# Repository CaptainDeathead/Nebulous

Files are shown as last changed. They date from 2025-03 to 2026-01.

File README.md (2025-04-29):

# Nebulous

Nebulous is a retro console system powered by a Raspberry Pi. Designed for both nostalgia and innovation, it offers a unique blend of custom hardware and software to deliver an exciting multiplayer gaming experience.

## Features

- **Custom Controllers**: Nebulous supports up to 4 controllers for multiplayer gaming.
- **SD Card Cartridges**: Games are loaded via SD card cartridges, offering a retro game-swapping experience.
- **3D Printed Shell**: The physical console is encased in a sleek and durable 3D-printed shell.
- **Custom Games**: Includes a variety of games designed specifically for Nebulous (see the list below).
- **NES Game Support**: Play classic `.nes` files for old NES games.

## Custom Games

The `games` directory contains the following games created specifically for Nebulous using Pygame:

- **Caliby**: A calibration tool for testing controllers with the Nebulous.
- **Meteors**: A 4-player Asteroids clone.
- **Pong**: The classic Pong game.
- **Shape Royale**: A class-based battle royale where you play as 2D shapes.
- **Snither**: A multiplayer merge of Slither.io and classic Snake.
- **Tetris**: A 4-player version of the timeless Tetris game.

## Design Files

All files related to the physical design of Nebulous are located in the `/design` directory, including:

- **3D Printing Files**: Models for the Nebulous shell.
- **Controller PCB Designs**: Schematics and layouts for custom controllers.
- **Wiring Designs**: Diagrams and plans for wiring the console, controllers, and other components.

## How It Works

- **Without Cartridge**: If no game cartridge is inserted, the console will prompt you to insert one.
- **With Cartridge**: When a cartridge is inserted, the console attempts to load and play the game.

## Getting Started

1. **Hardware Setup**:
   - Assemble the 3D-printed case using files from the `/design` directory.
   - Connect up to 4 custom controllers using the provided PCB and wiring designs.
   - Insert an SD card cartridge containing your desired game.

2. **Software Setup**:
   - Clone the repository:
     ```bash
     git clone https://github.com/CaptainDeathead/Nebulous.git
     ```
   - Navigate to the `rpi-install` directory and run the `install.sh` script to set up the console:
     ```bash
     cd Nebulous/rpi-install
     ./install.sh
     ```

3. **Running Games**:
   - Insert a game cartridge to start playing.
   - Alternatively, load a `.nes` file for older NES games.

## Contributing

Contributions are welcome! Feel free to submit pull requests or open issues for bug reports and feature suggestions.

## License

This project is licensed under the MIT License - see the [LICENSE](LICENSE) file for details.

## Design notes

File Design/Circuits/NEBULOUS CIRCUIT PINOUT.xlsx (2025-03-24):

USE | PIN INFO | PINS L | PINS R | PIN INFO | USE | USE | PINS L |  | PINS R | USE | USE | PINS
MAIN BRIDGE 3V POWER |  | 3.3V | 5V |  | CARTRIDGE READER 5V POWER | C0 DPAD + SELECT | CH0 |  | 3.3V IN | MAIN BRIDGE 3.3V POWER | MAIN BRIDGE 3.3V GND | GND
 | I2C | SDA | 5V |  |  | C0 ABXY + START | CH1 |  | 3.3V IN | MAIN BRIDGE 3.3V POWER | MAIN BRIDGE 3.3V POWER | 3.3V IN
 | I2C | SCL | GROUND |  | CARTRIDGE READER 5V GND | C1 DPAD + SELECT | CH2 |  | GND | MAIN BRIDGE 3.3V GND | CARTRIDGE READER 5V POWER | 5V IN
 |  | GPIO 4 | TX | UART |  | C1 ABXY + START | CH3 | MCP3008 | CLK | SPI BRIDGE - SCLK | CE1 GPIO 7 | CE1 | CARTRIDGE READER | CARTRIDGE
MAIN BRIDGE 3V GND |  | GROUND | RX | UART |  | C2 DPAD + SELECT | CH4 | MCP3008 | MISO | SPI BRIDGE - MSIO | SPI BRIDGE - MOSI | MOSI | CARTRIDGE READER | CARTRIDGE
 |  | GPIO 17 | GPIO 18 |  | CONSOLE FRONT ON / OFF SIGNAL | C2 ABXY + START | CH5 |  | MOSI | SPI BRIDGE - MOSI | SPI BRIDGE - SCLK | SCLK
 |  | GPIO 27 | GROUND |  |  | C3 DPAD + SELECT | CH6 |  | CE0 | CE0 GPIO 8 | SPI BRIDGE - MISO | MISO
 |  | GPIO 22 | GPIO 23 |  |  | C3 ABXY + START | CH7 |  | GND | MAIN BRIDGE 3.3V GND | CARTRIDGE READER 5V GND | GND
CONSOLE MANAGEMENT 3.3V POWER |  | 3.3V | GPIO 24
SPI BRIDGE - MCP3008 / CARTRIDGE READER | SPI | MOSI | GROUND
SPI BRIDGE - MCP3008 / CARTRIDGE READER | SPI | MISO | GPIO 25
SPI BRIDGE - MCP3008 / CARTRIDGE READER | SPI | SCLK | CE0 GPIO 8 | SPI | MCP3008 - CHIP SELECT
CONSOLE MANAGEMENT 3.3V GND |  | GROUND | CE1 GPIO 7 | SPI | CARTRIDGE READER - CHIP SELECT
 | RESERVED | GPIO 1 | GPIO 0 | RESERVED
CONTROLLER 0 STATUS INPUT |  | GPIO 5 | GROUND
CONTROLLER 1 STATUS INPUT |  | GPIO 6 | GPIO 12
CONTROLLER 2 STATUS INPUT |  | GPIO 13 | GROUND
CONTROLLER 3 STATUS INPUT |  | GPIO 19 | GPIO 16
 |  | GPIO 26 | GPIO 20
 |  | GROUND | GPIO 21

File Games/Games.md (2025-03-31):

# Game information for Nebulous

## Format
1. Games must be made in any way that involves a single graphical window that must run on a raspberry pi with no DE (Desktop Environment).
2. Games should be shipped in cartridges which will plug into the exterior of the console.
3. Games should be made compatible with at least one of the availiable controllers for the console.
4. Games should provide appropriate information of their age restrictions and content contained.

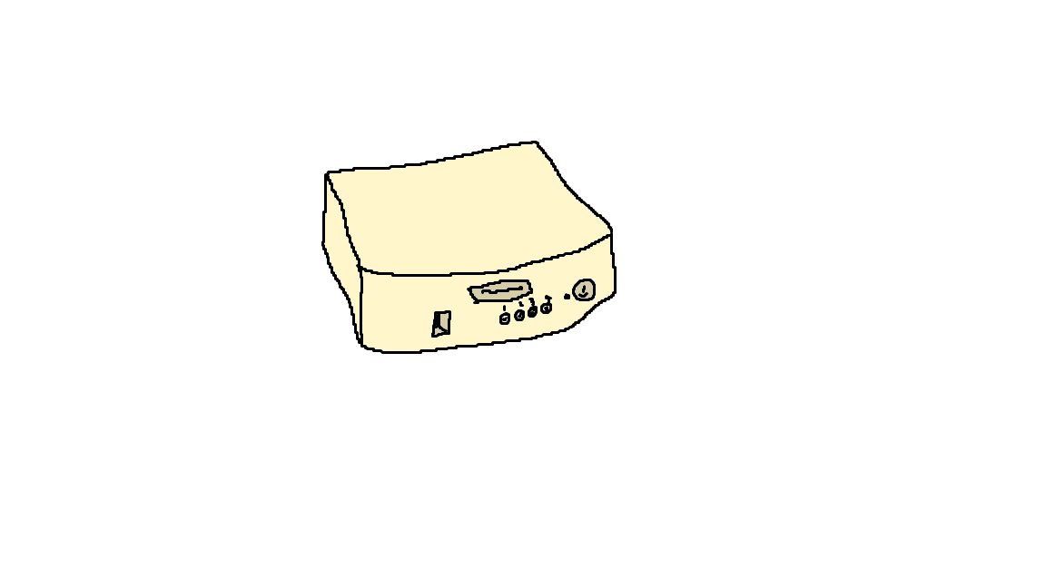
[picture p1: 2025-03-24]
Design/Sketches/CONSOLE BASE DESIGN.png

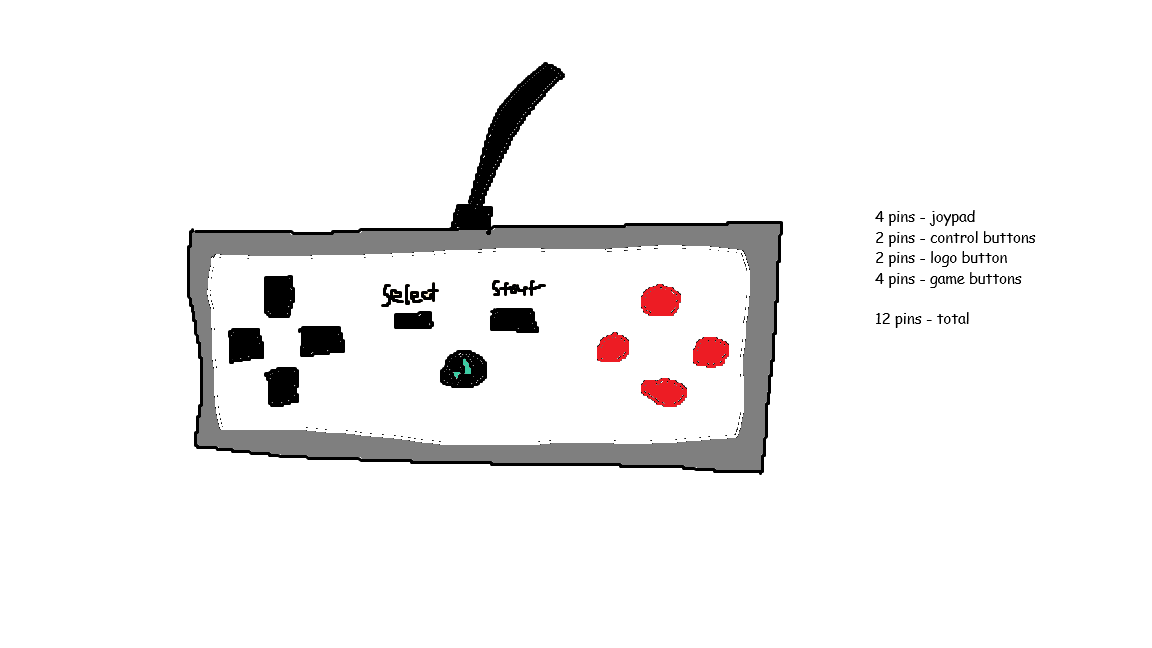
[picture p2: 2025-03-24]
Design/Sketches/CONTROLLER IDEA DESIGN (PINS NOT CORRECT).png

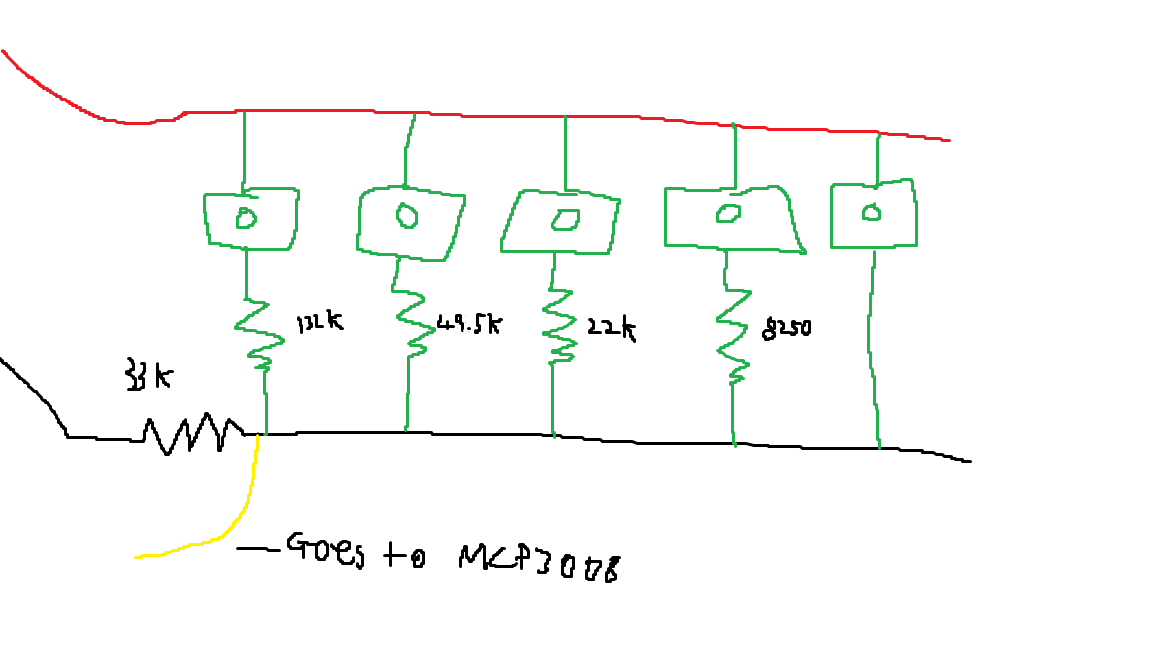
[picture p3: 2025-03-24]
Design/Sketches/ROUGH CONTROLLER CIRCUIT.png

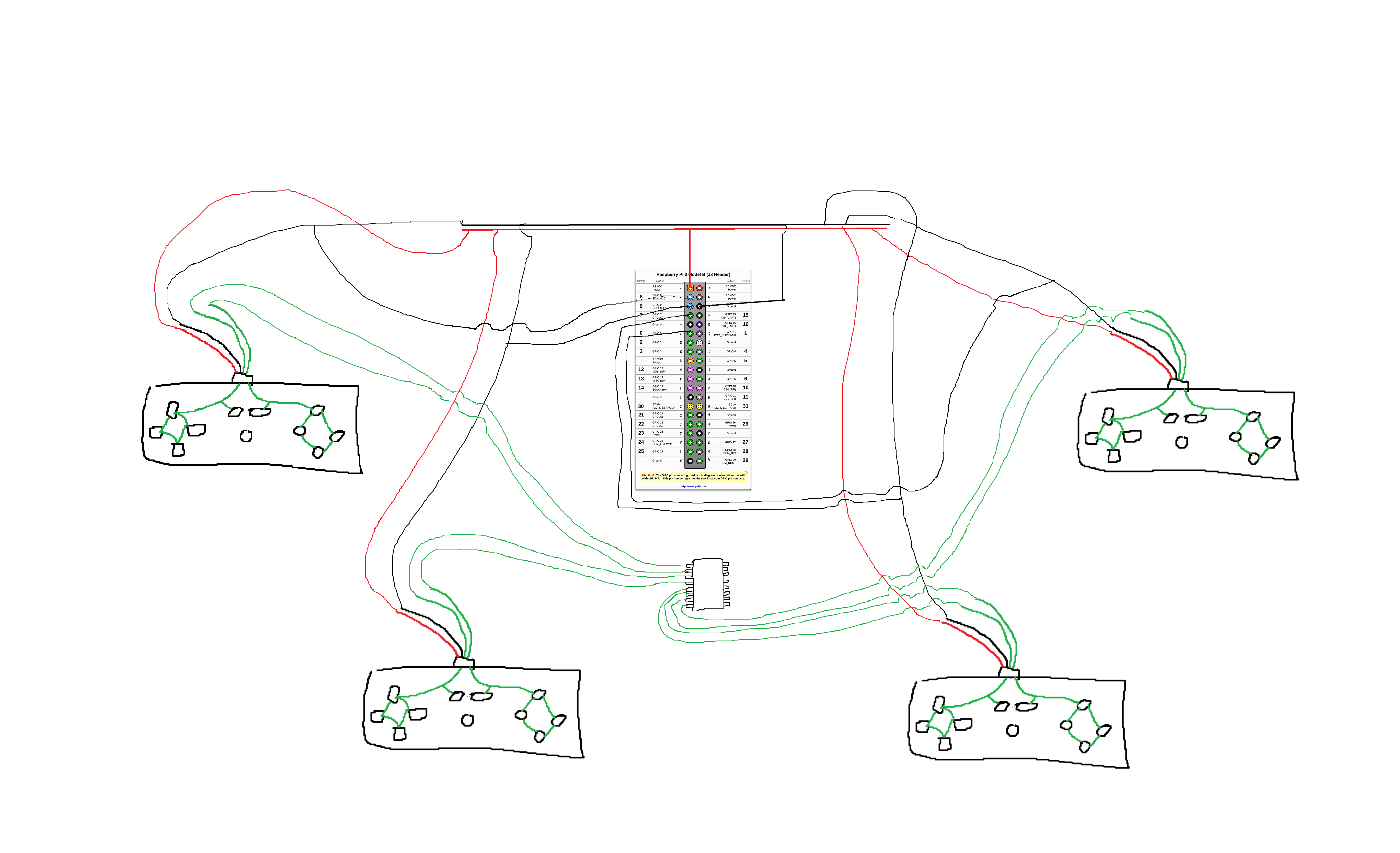
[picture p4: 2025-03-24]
Design/Sketches/ROUGH CIRCUIT (PINS NOT CORRECT).png

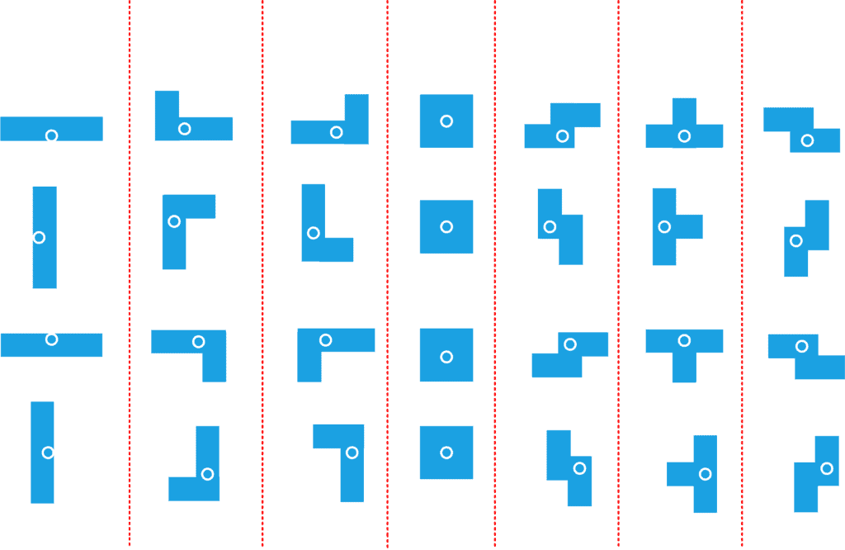
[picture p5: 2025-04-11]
Games/Tetris/rotations.png

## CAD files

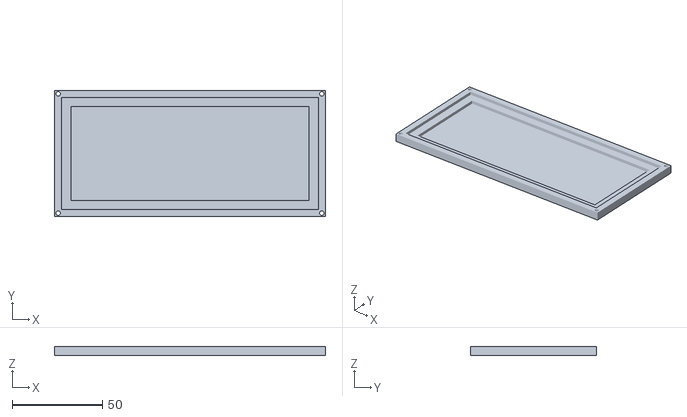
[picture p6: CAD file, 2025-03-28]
Design/Controller stls/Shell Bottom v3.stl
150.0 x 70.0 x 5.00

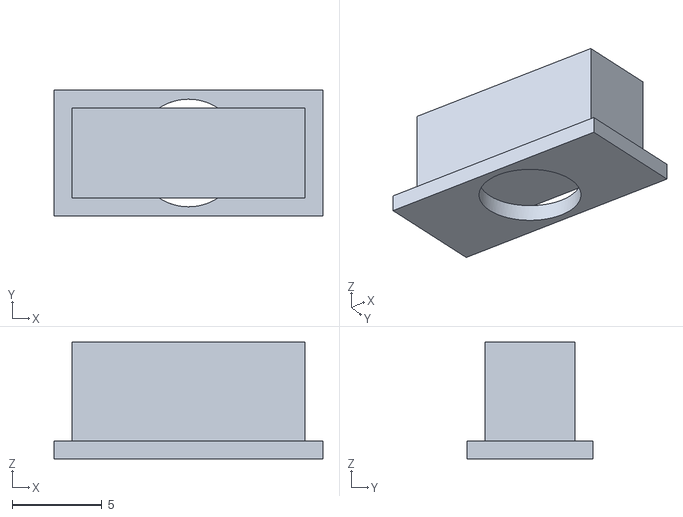
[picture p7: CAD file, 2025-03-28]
Design/Controller stls/Select-Start v1.stl
15.0 x 7.00 x 6.50

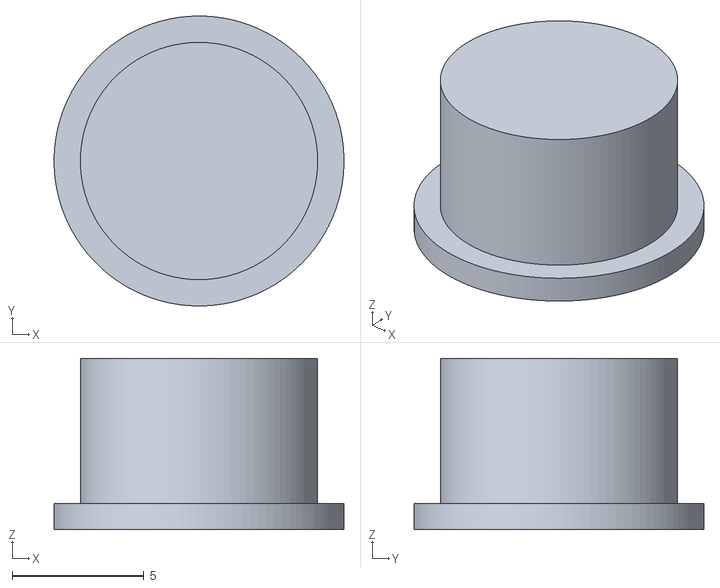
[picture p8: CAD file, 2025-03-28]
Design/Controller stls/ABCD v2.stl
11.0 x 11.0 x 6.50

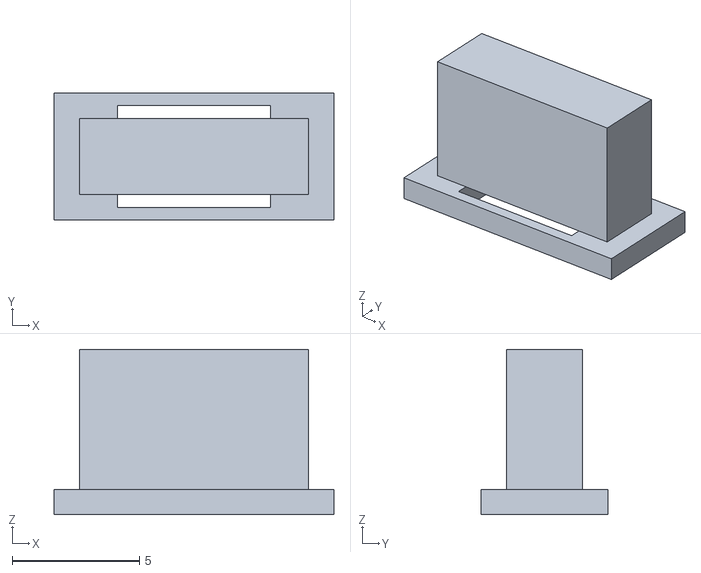
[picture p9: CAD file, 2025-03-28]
Design/Controller stls/D-Pad v1.stl
11.0 x 5.00 x 6.50

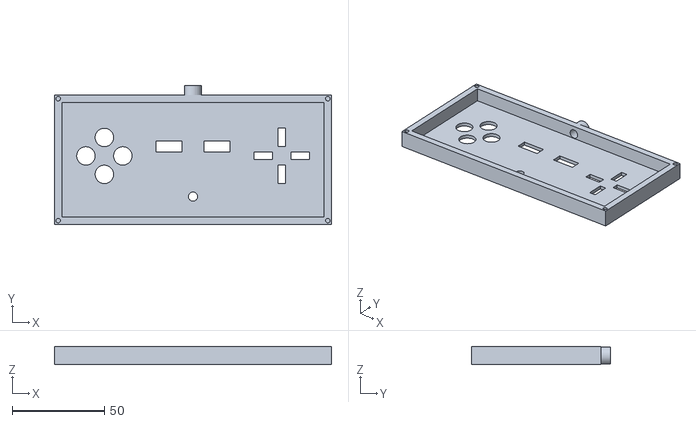
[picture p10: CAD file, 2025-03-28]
Design/Controller stls/Shell Top v5.stl
150.0 x 75.0 x 10.0

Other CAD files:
Design/Main Console stls/Nebulous Base.f3d
Design/Main Console stls/Nebulous Roof.f3d
Design/Main Console stls/Nebulous Visual (DO NOT USE IN PRINTER) v1.f3z

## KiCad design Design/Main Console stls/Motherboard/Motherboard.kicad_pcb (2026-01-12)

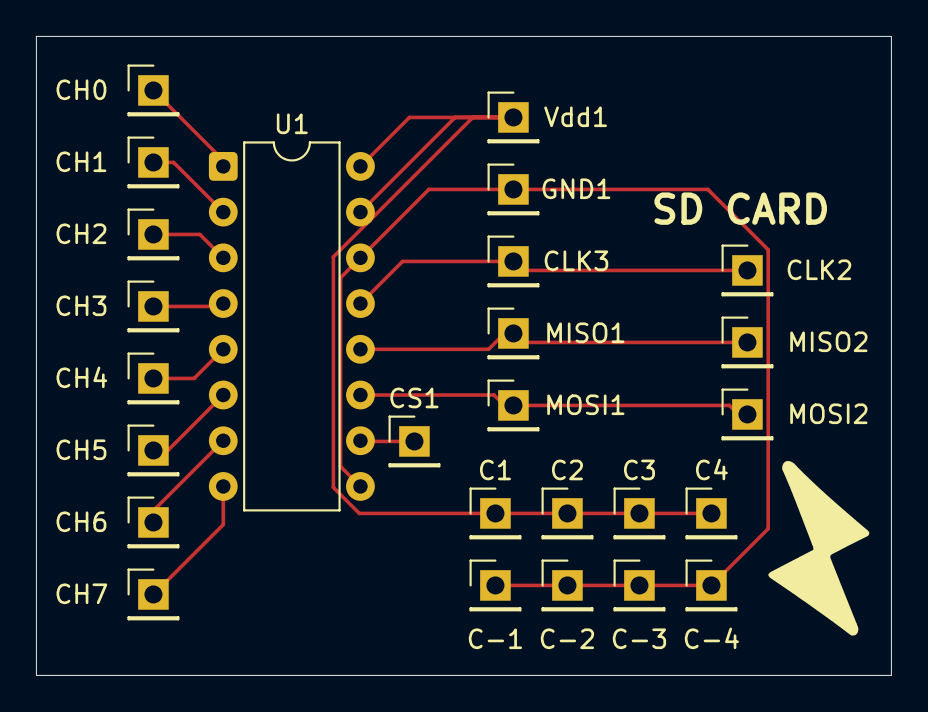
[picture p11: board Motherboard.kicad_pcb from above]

Board: 2 copper layers, 47.5 x 35.5 mm, 26 parts (0 on the bottom side), 14 nets.

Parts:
C1, C2, C3, C4: TestPoint; PinHeader_1x01_P2.54mm_Vertical
C-1, C-2, C-3, C-4: TestPoint; PinHeader_1x01_P2.54mm_Vertical
CH0, CH1, CH2, CH3, CH4, CH5, CH6, CH7: TestPoint; PinHeader_1x01_P2.54mm_Vertical
CLK2, CLK3: TestPoint; PinHeader_1x01_P2.54mm_Vertical
CS1: TestPoint; PinHeader_1x01_P2.54mm_Vertical
GND1: TestPoint; PinHeader_1x01_P2.54mm_Vertical
MISO1, MISO2: TestPoint; PinHeader_1x01_P2.54mm_Vertical
MOSI1, MOSI2: TestPoint; PinHeader_1x01_P2.54mm_Vertical
U1: MCP3008; DIP-16_W7.62mm
Vdd1: TestPoint; PinHeader_1x01_P2.54mm_Vertical

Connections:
unnamed: C-1.1, C-2.1, C-3.1, C-4.1, GND1.1, U1.9 (DGND), U1.14 (AGND)
unnamed: CH0.1, U1.1 (CH0)
unnamed: CH1.1, U1.2 (CH1)
unnamed: CH2.1, U1.3 (CH2)
unnamed: CH3.1, U1.4 (CH3)
unnamed: CH4.1, U1.5 (CH4)
unnamed: CH5.1, U1.6 (CH5)
unnamed: CH6.1, U1.7 (CH6)
unnamed: CH7.1, U1.8 (CH7)
unnamed: CLK2.1, CLK3.1, U1.13 (CLK)
unnamed: MOSI1.1, MOSI2.1, U1.11 (Din)
unnamed: MISO1.1, MISO2.1, U1.12 (Dout)
unnamed: C1.1, C2.1, C3.1, C4.1, U1.15 (Vref), U1.16 (Vdd), Vdd1.1
unnamed: CS1.1, U1.10 (~CS/SHDN)

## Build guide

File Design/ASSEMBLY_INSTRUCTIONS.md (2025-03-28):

# Quick & Easy Recipe for a Flavourful Nebulous

## Ingredients:
- 1x MCP3008 ADC
- 1x Breadboard
- 1x Raspberry Pi (any / 3a+ suggested minimum requirement)
- 1x XC4386 Arduino Compatable SD card interface module
- 4x Nebulous Controller PCB (or breadboarded equivilent)
- 40x Those specific switches (or breadboard equivilent __Only if not using the pcb__)
- 8x 33kΩ resistors
- 8x 8250Ω resistors
- 8x 22kΩ resistors
- 8x 49500Ω resistors
- 8x 132kΩ resistors
- 4x 4 pin socket (any type)
- 4x 4 pin plug (matching socket)
- 4x Generic led
- 4x Resistor matching generic led
- 1x Nebulous Base 3d Printed
- 1x Nebulous Roof 3d Printed
- 16x ABCD 3d Printed
- 16x D-Pad 3d Printed
- 8x Select-Start 3d Printed
- 4x Controller Shell top 3d Printed
- 4x Controller Shell bottom 3d Printed

## Method:
> [!NOTE]
> If not using a pcb for the controller, ignore step 1 and see the bottom of the page for alternative instructions on breadboarding.
1. For each Nebulous Controller PCB, soldier in all the buttons and resistors into their labeled positions, as well as the generic led. Soldier the ends of the positive, ground, data 1, and data 2 wires to the pcb in their respective positions.
2. Screw each Nebulous Controller PCB into a Controller Shell Bottom. Thread the wires connected to the pcb through the outgoing hole in the controller shell top. 
3. Place the ABCD, D-Pad, Select and Start buttons into the controller shell top, and carefully place the controller bottom onto the top, and pull the wires through the hole. Repeat for each controller.
4. Screw the Controller Shell pieces together using the screw holes on the corners. Soldier the wires from each controller to a 4 pin connector. The controllers are now complete.
5. to be continuted

> [!CAUTION]
> Scary

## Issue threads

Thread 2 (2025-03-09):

Snither win condition

Something231, 2025-03-09:
If all players die before the ai, an ai will win by domination even if it has done pretty much nothing, a win by score victory should be added so the snake with the highest score wins when all players die before the ai do.

Closed 2025-03-15.

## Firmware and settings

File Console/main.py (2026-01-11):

import pygame as pg
import random
import logging
import os

from Controllers.controller import Controller
from Controllers.controller_manager import ControllerManager
from cartridge_loader import CartridgeLoader
from console_io import IOManager
from time import sleep, time
from threading import Thread
from sys import argv
from traceback import format_exc

logging.basicConfig()
logging.root.setLevel(logging.DEBUG)
logging.basicConfig(level=logging.DEBUG)

FONTS_PATH = "./UI/Fonts"

class Console:
    """
    FIRMWARE FOR NEBULOUS CONSOLE
    """

    CONSOLE_NAME = "Nebulous REV. A - PROTO"
    TARGET_FIRMWARE_INFO = {
        "CONSOLE_NAME": CONSOLE_NAME,
        "HOST_TYPE": "Linux - Raspberry Pi OS DESKTOP",
        "FIRMWARE_VERSION": "1.1.0",
        "REQUIREMENTS": ["Restart console to load new cartridge (auto detection causing controller lag)"]
    }

    # Allows the console to write data to the cartridge, and verify it is the same to check if cartridge is still inserterd
    # WARNING: THIS CAN CAUSE INTERUPTIONS TO THE CONTROLLER INPUTS (DELAY + GHOSTING)
    # WARNING: THIS CAN HAVE INCONSISTENT BEHAVIOUR WHEN PAIRED WITH CONTROLLERS (RANDOM FAILED READS / WRITES)
    CARTRIDGE_READ_CHECK = False
    USE_CONTROLLER_THREAD = False

    NUM_CONTROLLER_PORTS = 4
    TARGET_FPS = 60 # Only affects menu
    TESTING = False # Allows testing in a non-console environment

    def __init__(self, testing: bool = False, flashing: bool = False) -> None:
        """
        Steps to initialize console:
        1. Initialize console input / output devices (io)
        2. Initialize controllers and controller polling
        3. Initialize display and screen
        4. Load into blank console interface
        5. Initialize cartridge loading
        """

        self.init = False
        self.TESTING = testing
        self.FLASHING = flashing

        logging.info("Welcome from the console!!!\n")

        for key, value in self.TARGET_FIRMWARE_INFO.items():
            logging.info(f"{key}: {value}")

        print()

        self.init_io()
        self.init_controllers()
        self.init_display()
        self.init_menu_interface()
        self.init_cartridges()

        # All threads will read this every time they update and safely shutdown if it is True.
        # Used to shutdown console safely.
        self.kill_threads = False

        self.update_controllers = False # Allows for cartridge reader to "read check" its status 'safely'.
        self.controller_check_thread = Thread(target=self.check_controllers)
        if self.USE_CONTROLLER_THREAD:
            self.controller_check_thread.start()

        self.last_cartridge_update_check = 0
        self.cartridge_check_thread = Thread(target=self.check_cartridge)
        self.cartridge_check_thread.start()

        self.init = True
        logging.info("Console startup complete!")

        if self.TESTING or 1: self.load_cartidge()

        self.main()

    def final_console_shutdown(self) -> None:
        logging.info("Recieved shutdown signal! Don't leave me!!!")

        logging.debug("Waiting for threads to shutdown...")
        self.kill_threads = True
        self.cartridge_check_thread.join()
        if self.USE_CONTROLLER_THREAD:
            self.controller_check_thread.join()

        self.cartridge_loader.unload_cartridge()

        logging.info("Executing 'Nebulous:/Console$ sudo shutdown now'...")
        os.system("sudo shutdown now") # WARNING: Requires 'sudo' to not have a password
        exit(0)

    def init_io(self) -> None:
        logging.info("Initializing console io manager...")

        self.io_manager = IOManager(self.TESTING, self.final_console_shutdown)

    def init_controllers(self) -> None:
        logging.info("Initializing controllers...")

        self.controller_manager = ControllerManager(testing=self.TESTING)

    def init_display(self) -> None:
        logging.info("Initializing display...")

        pg.init()

        try:
            pg.mixer.init(size=32)
        except:
            logging.error("Failed to initialize audio!")
            logging.error(format_exc())


        self.pygame_info = pg.display.Info()
        self.WIDTH = self.pygame_info.current_w
        self.HEIGHT = self.pygame_info.current_h

        self.screen = pg.display.set_mode((self.WIDTH, self.HEIGHT), pg.FULLSCREEN | pg.DOUBLEBUF | pg.HWSURFACE, display=0)

        self.clock = pg.time.Clock()

        pg.mouse.set_visible(False)

    def init_menu_interface(self) -> None:
        logging.info("Initializing menu interface...")

        font = pg.font.Font(f"{FONTS_PATH}/PressStart2P.ttf", 30)

        self.enter_cartridge_surf = font.render("Enter game cartridge...", True, (255, 255, 255))
        self.enter_cartridge_rect = pg.Rect(self.WIDTH // 2 - self.enter_cartridge_surf.width // 2, self.HEIGHT // 2 - self.enter_cartridge_surf.height // 2, self.enter_cartridge_surf.width, self.enter_cartridge_surf.height)
        self.enter_cartridge_vel = [random.choice([3, -3]), random.choice([3, -3])]

    def init_cartridges(self) -> None:
        logging.info("Initializing cartridges...")

        self.cartridge_loader = CartridgeLoader(self.on_title_launch, self.FLASHING)
        self.cartridge_loaded = False

    def load_cartidge(self) -> None:
        self.cartridge_loader.load_cartridge()

    def check_controllers(self) -> None:
        while not self.kill_threads:
            if not self.update_controllers:
                sleep(0.01)
                continue

            self.controller_manager.update()
            sleep(0.01)

    def check_cartridge(self) -> None:
        if self.TESTING: return

        last_cartridge_loaded = self.cartridge_loaded

        while self.cartridge_loader.init_failure:
            if self.kill_threads: return

            self.update_controllers = False

            logging.warning("Attempting to restart cartridge loadeder to reset SD loader (init failure)...")
            self.cartridge_loader.__init__(self.on_title_launch)

            if self.cartridge_loader.init_failure:
                logging.error("Failed to re-init cartridge loader! Waiting 1 second before retrying...")
                sleep(1)

        while not self.kill_threads:
            if self.CARTRIDGE_READ_CHECK:
                if time() - self.last_cartridge_update_check > 2:
                    self.last_cartridge_update_check = time()

                    self.update_controllers = False
                    cartridge_loaded = self.cartridge_loader.is_sd_card_connected()
                    self.update_controllers = True

                    if cartridge_loaded is not None: self.cartridge_loaded = cartridge_loaded

                else:
                    sleep(time() - self.last_cartridge_update_check)

            if not self.cartridge_loaded and self.CARTRIDGE_READ_CHECK:
                self.on_cartridge_remove()
                self.init_cartridges()
                self.check_cartridge()
                return

            elif not last_cartridge_loaded:
                self.cartridge_loaded = True

                if not self.CARTRIDGE_READ_CHECK:
                    logging.warning("Cartridge read checking disabled! Killing cartridge check thread...")
                    return

            #if self.cartridge_loaded: return

    def on_cartridge_remove(self) -> None:
        logging.warning(f"Cartridge no longer reading / writing (disconnected)!")

    def on_game_crash(self) -> None:
        self.screen.fill((255, 0, 0))
        
        title_font = pg.font.Font(f"{FONTS_PATH}/PressStart2P.ttf", 50)
        self.screen.blit(title_font.render("GAME CRASH!", True, (255, 255, 255)), (100, 100))

        instructions_font = pg.font.Font(f"{FONTS_PATH}/PressStart2P.ttf", 30)
        self.screen.blit(instructions_font.render("Restart the console using the front IO switch to safely recover.", True, (0, 255, 255), wraplength=self.WIDTH - 100), (100, 200))

        error_font = pg.font.Font(f"{FONTS_PATH}/PressStart2P.ttf", 20)
        self.screen.blit(error_font.render(f"Error:\n{format_exc()}", True, (0, 0, 0), wraplength=self.WIDTH - 200), (100, 300))

        pg.display.flip()
        
        while 1:
            self.clock.tick(self.TARGET_FPS)

            for event in pg.event.get():
                ...

            self.update()

    def main(self) -> None:
        while not self.cartridge_loaded:
            self.delta_time = self.clock.tick(self.TARGET_FPS)
            self.screen.fill((0, 0, 0))

            for event in pg.event.get():
                if event.type == pg.QUIT:
                    pass

            self.update()

            self.enter_cartridge_rect = self.enter_cartridge_rect.move(self.enter_cartridge_vel[0], self.enter_cartridge_vel[1])

            # Bounce of walls
            if self.enter_cartridge_rect.x <= 0:
                self.enter_cartridge_rect = pg.Rect(0, self.enter_cartridge_rect.y, self.enter_cartridge_rect.w, self.enter_cartridge_rect.h)
                self.enter_cartridge_vel[0] *= -1

            elif self.enter_cartridge_rect.x + self.enter_cartridge_rect.w >= self.WIDTH:
                self.enter_cartridge_rect = pg.Rect(self.WIDTH - self.enter_cartridge_rect.w, self.enter_cartridge_rect.y, self.enter_cartridge_rect.w, self.enter_cartridge_rect.h)
                self.enter_cartridge_vel[0] *= -1

            if self.enter_cartridge_rect.y <= 0:
                self.enter_cartridge_rect = pg.Rect(self.enter_cartridge_rect.x, 0, self.enter_cartridge_rect.w, self.enter_cartridge_rect.h)
                self.enter_cartridge_vel[1] *= -1

            elif self.enter_cartridge_rect.y + self.enter_cartridge_rect.h >= self.HEIGHT:
                self.enter_cartridge_rect = pg.Rect(self.enter_cartridge_rect.x, self.HEIGHT - self.enter_cartridge_rect.h, self.enter_cartridge_rect.w, self.enter_cartridge_rect.h)
                self.enter_cartridge_vel[1] *= -1

            self.screen.blit(self.enter_cartridge_surf, self.enter_cartridge_rect)

            pg.display.flip()

        self.load_cartidge()
        self.main() # Reset when the game stops (cartridge unloaded)

    def update(self) -> bool:
        """Returns: should_quit"""

        self.io_manager.set_led_on()
        self.io_manager.update()
        self.controller_manager.update()
        
        if self.cartridge_loaded == False: return True

        return False

    def on_title_launch(self, ConsoleEntry: object) -> None:
        while not self.init:
            sleep(0.1)

        self.cartridge_loaded = True
        self.update_controllers = True

        try:
            ConsoleEntry(self.screen, self.update, self.controller_manager.get_num_players, self.controller_manager.controllers)
        except Exception as e:
            logging.error(f"Game crashed with error: {e}!")

            logging.error(format_exc())
            
            # If the user cannot recover by unplugging cartridge then show crash screen
            if not self.CARTRIDGE_READ_CHECK:
                self.on_game_crash()
            else:
                self.main()

if __name__ == "__main__":
    # Where it all begins...
    testing = False # DO NOT CHANGE THIS VALUE!!!!! USE --test WHEN RUNNING THE SCRIPT FOR TESTING
    flashing = False

    if len(argv) > 1:
        if argv[1] == "--test":
            testing = True
        elif argv[1] == "--flash":
            flashing = True
        else:
            raise Exception(f"Argument {argv[1]} is not recognised! Use --test for console testing. Use --flash for cartridge flashing.")

    console = Console(testing, flashing)

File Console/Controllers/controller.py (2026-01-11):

import logging

try:
    import uinput
    from adafruit_mcp3xxx.analog_in import AnalogIn
    import RPi.GPIO as GPIO
    TESTING = False
except:
    def AnalogIn(**args) -> None: ...

    class GPIO:
        @staticmethod
        def setup(a, b, pull_up_down=0) -> None:
            return None
    
        @staticmethod
        def input(a) -> bool:
            return False

    TESTING = True
    logging.error("Failed to import gpiozero library for controller interfaceing! Assuming this is a non-console test so continuing...")

from typing import List, Generator

class DPAD_CONTROLS:
    UP = 0
    RIGHT = 1
    DOWN = 2
    LEFT = 3

class ABXY_CONTROLS:
    A = 6
    B = 7
    X = 8
    Y = 9

class CONTROLS:
    DPAD = DPAD_CONTROLS
    SELECT = 4
    START = 5
    ABXY = ABXY_CONTROLS

    @staticmethod
    def get_control_str(control: int) -> str:
        match control:
            case 0: return "DPAD UP"
            case 1: return "DPAD RIGHT"
            case 2: return "DPAD DOWN"
            case 3: return "DPAD LEFT"
            case 4: return "SELECT"
            case 5: return "START"
            case 6: return "A"
            case 7: return "B"
            case 8: return "X"
            case 9: return "Y"

    @staticmethod
    def get_uinput_control_type(control: int) -> ...:
        match control:
            case 0: return uinput.BTN_DPAD_UP
            case 1: return uinput.BTN_DPAD_RIGHT
            case 2: return uinput.BTN_DPAD_DOWN
            case 3: return uinput.BTN_DPAD_LEFT
            case 4: return uinput.BTN_SELECT
            case 5: return uinput.BTN_START
            case 6: return uinput.BTN_A
            case 7: return uinput.BTN_B
            case 8: return uinput.BTN_X
            case 9: return uinput.BTN_Y

class ActualEvent:
    def __init__(self, type: int) -> None:
        self.type = type

class Event:
    def __init__(self) -> None:
        self.events = []

        self.device_event_types = [
            uinput.BTN_A,
            uinput.BTN_B,
            uinput.BTN_X,
            uinput.BTN_Y,
            uinput.BTN_DPAD_UP,
            uinput.BTN_DPAD_RIGHT,
            uinput.BTN_DPAD_DOWN,
            uinput.BTN_DPAD_LEFT,
            uinput.BTN_SELECT,
            uinput.BTN_START
        ]
        self.device = uinput.Device(self.device_event_types)

        self.events_this_frame = []

    def get(self) -> Generator[any, any, any]:
        # Returns the events in the contoller and clears them
        for event in self.events:
            yield event
            self.events.remove(event)

    def register(self, event: int) -> None:
        logging.debug(f"Controller recieved {CONTROLS.get_control_str(event)}.")

        self.events.append(ActualEvent(event))
        self.events_this_frame.append(event)

        self.device.emit(CONTROLS.get_uinput_control_type(event), 1)

    def reset_uinput(self) -> None:
        for i in range(10):
            if i not in self.events_this_frame:
                self.device.emit(CONTROLS.get_uinput_control_type(i), 0)

        self.events_this_frame = []

    def flush(self) -> None:
        self.events = []

class Controller:
    def __init__(self, port: int, left_channel: AnalogIn, right_channel: AnalogIn, status_pin: int, testing: bool = TESTING) -> None:
        self.port = port 
        
        self.left_channel = left_channel
        self.right_channel = right_channel

        self.status_pin = status_pin

        if not testing:
            GPIO.setmode(GPIO.BCM)
            GPIO.setup(self.status_pin, GPIO.IN, pull_up_down=GPIO.PUD_DOWN)
        else:
            logging.warning("Testing arg recieved so skipping controller pin init!")

        self.last_plugged_in = False
        self.plugged_in = False

        self.testing = testing
        #print(self.testing)

        self.event = Event()

    def on_plug(self) -> None:
        logging.info(f"Controller : {self.port} plugged in!")
        self.plugged_in = True

    def on_unplug(self) -> None:
        logging.info(f"Controller : {self.port} unplugged!")
        self.plugged_in = False

    def split_channel_value(self, ch_value: float, value: float, tolerance: float = 0.05) -> bool:
        if value > ch_value - tolerance and value < ch_value + tolerance:
            return True

        return False

    def poll_events(self) -> None:
        if self.testing: return

        #self.plugged_in = GPIO.input(self.status_pin)

        if self.plugged_in != self.last_plugged_in:
            if self.plugged_in: self.on_plug()
            else: self.on_unplug()

            self.last_plugged_in = self.plugged_in

        #if not self.plugged_in: return

        left_ch_value = self.left_channel.voltage / 3.3
        right_ch_value = self.right_channel.voltage / 3.3

        d_up = self.split_channel_value(left_ch_value, 0.2)
        d_left = self.split_channel_value(left_ch_value, 0.4)
        d_down = self.split_channel_value(left_ch_value, 0.6, tolerance = 0.04)
        d_right = self.split_channel_value(left_ch_value, 0.8, tolerance = 0.15)
        select = self.split_channel_value(left_ch_value, 1.0, tolerance = 0.04)

        y = self.split_channel_value(right_ch_value, 0.2)
        b = self.split_channel_value(right_ch_value, 0.4)
        a = self.split_channel_value(right_ch_value, 0.6, tolerance = 0.04)
        x = self.split_channel_value(right_ch_value, 0.8, tolerance = 0.15)
        start = self.split_channel_value(right_ch_value, 1.0, tolerance = 0.04)

        if d_up: self.event.register(CONTROLS.DPAD.UP)
        if d_right: self.event.register(CONTROLS.DPAD.RIGHT)
        if d_down: self.event.register(CONTROLS.DPAD.DOWN)
        if d_left: self.event.register(CONTROLS.DPAD.LEFT)
        if select: self.event.register(CONTROLS.SELECT)

        if a: self.event.register(CONTROLS.ABXY.A)
        if b: self.event.register(CONTROLS.ABXY.B)
        if x: self.event.register(CONTROLS.ABXY.X)
        if y: self.event.register(CONTROLS.ABXY.Y)
        if start: self.event.register(CONTROLS.START)

        self.event.reset_uinput()

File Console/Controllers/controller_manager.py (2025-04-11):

import logging

try:
    #from gpiozero import Device
    #from gpiozero.pins.pigpio import PiGPIOFactory

    #Device.pin_factory = PiGPIOFactory()

    #from gpiozero import MCP3008
    import busio
    import digitalio
    import board
    import adafruit_mcp3xxx.mcp3008 as MCP
    from adafruit_mcp3xxx.analog_in import AnalogIn

    import RPi.GPIO as GPIO
except:
    def MCP3008(**args) -> None: ...
    logging.error("Failed to import gpiozero library for controller interfaceing! Assuming this is a non-console test so continuing...")

def ErrMCP3008(**args) -> None: ...

from Controllers.controller import Controller

class ControllerManager:
    NUM_CONTROLLER_PORTS = 4

    CONTROLLER_STATUS_PINS = {
        0: 5,
        1: 6,
        2: 13,
        3: 19
    }

    def __init__(self, testing: bool = False) -> None:
        self.TESTING = testing

        try:
            GPIO.setmode(GPIO.BCM)

            self.spi = busio.SPI(clock=board.SCK, MISO=board.MISO, MOSI=board.MOSI)
            self.cs = digitalio.DigitalInOut(board.D8)
            self.mcp = MCP.MCP3008(self.spi, self.cs)

            #self.controllers = [
            #    Controller(i, MCP3008(channel=i*2, select_pin=8), MCP3008(channel=i*2+1, select_pin=8), self.CONTROLLER_STATUS_PINS[i], testing=self.TESTING)
            #    for i in range(self.NUM_CONTROLLER_PORTS)
            #]

            MCPPins = [MCP.P0, MCP.P1, MCP.P2, MCP.P3, MCP.P4, MCP.P5, MCP.P6, MCP.P7]

            self.controllers = []

            for i in range(self.NUM_CONTROLLER_PORTS):
                a = MCPPins[i*2]
                b = MCPPins[i*2+1]
                self.controllers.append(Controller(i, AnalogIn(self.mcp, a), AnalogIn(self.mcp, b), self.CONTROLLER_STATUS_PINS[i], testing=0))

        except Exception as e:
            logging.error(f"MCP3008 (Controller Managemnet Device) - Not Found! Error: {e}. No controllers working...")

            self.controllers = [
                Controller(i, ErrMCP3008(channel=i*2, select_pin=8), ErrMCP3008(channel=i*2+1, select_pin=8), self.CONTROLLER_STATUS_PINS[i], testing=self.TESTING)
                for i in range(self.NUM_CONTROLLER_PORTS)
            ]

    def get_num_players(self) -> int:
        num_players = 0

        for controller in self.controllers:
            if controller.plugged_in: num_players += 1

        return num_players

    def update(self) -> None:
        for controller in self.controllers:
            controller.poll_events()

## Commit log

2025-03-06 Basic setup script for raspberry pis
2025-03-08 Fixed bug to do with self.enter_cartridge_surf.height also added some files for upcoming additions
    [main.py]
2025-03-09 Fixed importing in cartridge_loader
    [cartridge_loader.py]
2025-03-09 Added duel SPI support
2025-03-10 Fix no self argument in controller.py
    [controller.py]
2025-03-11 Controller events using correct class
    [controller.py]
2025-03-15 Added some games and fixed ai for snither
    [cartridge_loader.py, main.py]
2025-03-15 Fixed grow and win conditions
    [main.py]
2025-03-15 Fixed space bug with timeout
    [main.py]
2025-03-15 Bug fixes + infinite mode snither
    [main.py]
2025-03-24 Added Design/ files
    [NEBULOUS CIRCUIT PINOUT.xlsx, Nebulous Base.f3d, Nebulous Roof.f3d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]
2025-03-25 Shape Royale balancing and ability fixes
    [main.py]
2025-03-26 GPIO config pin for controllers
2025-03-26 Debugging for GPIO pin
2025-03-26 GPIO pin pull_down
2025-03-26 Working controller switching
2025-03-28 Large changes to design directory
    [ABCD v2.stl, D-Pad v1.stl, NEBULOUS CIRCUIT PINOUT.xlsx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]
2025-03-28 added gerber file for controller + added method
2025-04-06 Pong; Game crash screen; Extra console info
    [cartridge_loader.py, main.py]
2025-04-07 Fix cartridge unload check
    [main.py]
2025-04-11 Added --flash arg, removed controller update thread, fixed snither main menu spam inputs
    [cartridge_loader.py, controller.py, main.py]
2026-01-12 Made v1 motherboard
    [Motherboard-B_Cu.gbr, Motherboard-B_Mask.gbr, Motherboard-B_Paste.gbr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]
